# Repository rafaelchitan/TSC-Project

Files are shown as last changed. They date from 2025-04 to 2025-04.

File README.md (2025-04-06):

# Proiect TSC

## Chitan Rafael-Alexandru - 332CA

# Diagrama block

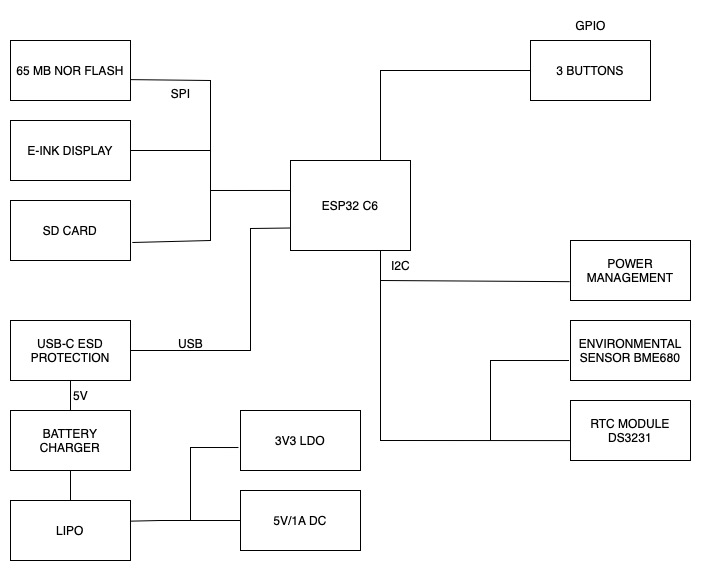
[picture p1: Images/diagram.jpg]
Diagrama


# Descrierea componentelor hardware

## Microcontroller – ESP32-C6

- **Arhitectura:** RISC-V 32-bit
- **Conectivitate:** WiFi 6, Bluetooth Low Energy 5.0
- **Interfete:** SPI, I2C, UART, PWM, GPIO
- **Consum redus:** suporta moduri de somn (deep sleep)

---

## E-Paper Display

- **Conectare:** 20 pini prin header dedicat
- **Control:** SPI + GPIO
  - Semnale: `EPD_CS`, `EPD_DC`, `EPD_RST`, `EPD_BUSY`, etc.
- **Avantaje:** consum 0 in standby, lizibilitate excelenta in lumina naturala

---

## Senzor de Mediu – BME688

- **Functii:** Temperatura, Umiditate, Presiune, Calitate aer (VOCs)
- **Comunicare:** I2C
  - SDA: `IO1`
  - SCL: `IO2`
- **Tensiune:** 3.3V
- **Adresa I2C:** `0x76`

---

## RTC – DS3231SN

- **Functie:** Timp real cu precizie ±2 ppm
- **Interfata:** I2C (SDA/SCL comune)
- **Backup:** Supercapacitor

---

## Alimentare si Baterie

### MAX17048 – Fuel Gauge

- **Functie:** Monitorizare nivel baterie LiPo
- **Comunicare:** I2C (`IO1`, `IO2`)

### MCP73831 – Battery Charging Controller

- **Incarcare:** 1 celula LiPo (USB → 3.7V)
- **Curent:** ~500 mA
- **Status LED:** Incarcare finalizata / in curs

### XC6204 – LDO Regulator

- **Intrare:** 5V (USB)
- **Iesire:** 3.3V
- **Curent maxim:** 200 mA
- **Consum in standby:** < 1 µA

---

## Stocare

### SD Card (microSD)

- **Interfata:** SPI (IO4–IO9)
- **Functie:** Salvare fisiere eBook, configurari

### NOR Flash – W25Q512JV (64MB)

- **Interfata:** SPI (dedicat: IO20–IO23)
- **Functie:** Stocare firmware, fonturi, assets

---

## Voltage Supervisor & Reset

- **Componenta:** BD52xx
- **Functie:** Monitorizare tensiune si reset sigur
- **Boot/Reset GPIO:** `IO0`

---

## I2C Extensii – Qwiic / Stemma QT

- **Conector:** 4 pini (3V3, GND, SDA, SCL)
- **Interfata:** I2C (`IO1`, `IO2`)
- **Compatibil:** Adafruit / SparkFun senzori si periferice

---

## Estimare Consum de Energie

| Componenta | Activ | Standby |
|---|---|---|
| ESP32-C6 | 80–150 mA | <10 µA |
| E-Paper | 20–30 mA | 0 µA |
| BME688 | 1.1 mA | 0.15 µA |
| RTC DS3231SN | 200 µA | 2 µA |
| SD Card | 20–100 mA | 0.2 µA |
| MAX17048 | 50 µA | 1 µA |
| NOR Flash | 20 mA | 5 µA |

---

## Test Pads & Protectie ESD

- **Protectii:** TVS diode pe USB, SPI si I2C
- **Test Pads:** disponibile pentru debugging si masuratori

---

## Pin Mapping – ESP32-C6

| Functie | GPIO Pins |
|---|---|
| SD Card (SPI) | IO4, IO5, IO6, IO9  |
| E-Paper Display | IO10–IO19 |
| I2C (RTC, Sensor, Fuel)| IO1 (SDA), IO2 (SCL)|
| SPI Flash extern | IO20–IO23 |
| Reset / Boot Button | IO0 |

## Bill of Materials
| Componenta | Link | Datasheet |
|---|---|---|
| BUTTON | [Model](https://industry.panasonic.com/global/en/products/control/switch/light-touch/number/evqpuj02k) | [Datasheet](https://www.lcsc.com/datasheet/lcsc_datasheet_2201121800_PANASONIC-EVQPUJ02K_C2936858.pdf) |
| CAPACITOR | [Model](https://componentsearchengine.com/part-view/R0402%201%25%20100%20K%20(RC0402FR-07100KL)/YAGEO) | [Datasheet](//efaidnbmnnnibpcajpcglclefindmkaj/https://www.resistor.com/assets/pdf/0402tstd.pdf) |
| CPH3225A | [Model](https://www.snapeda.com/parts/CPH3225A/Seiko+Instruments/view-part/?ref=eda) | [Datasheet](https://octopart.com/datasheet/cph3225a-seiko-25340571) |
| EVQPUJ02K | [Model](https://industry.panasonic.com/global/en/products/control/switch/light-touch/number/evqpuj02k) | [Datasheet](https://www.lcsc.com/datasheet/lcsc_datasheet_2201121800_PANASONIC-EVQPUJ02K_C2936858.pdf) |
| KP-1608SURCK | [Model](https://www.snapeda.com/parts/KP-1608SURCK/Kingbright/view-part/?ref=search&t=LED%200603) | [Datasheet](//efaidnbmnnnibpcajpcglclefindmkaj/https://media.elv.com/file/107153_led_surck1608_data.pdf) |
| USBLC6-2SC6Y | [Model](https://www.snapeda.com/parts/USBLC6-2SC6Y/STMicroelectronics/view-part/?ref=eda) | [Datasheet](https://www.digikey.com/en/htmldatasheets/production/1375342/0/0/1/usblc6-2sc6y) |
| SD0805S020S1R0 | [Model](https://ro.mouser.com/ProductDetail/KYOCERA-AVX/SD0805S020S1R0?qs=jCA%252BPfw4LHbpkAoSnwrdjw%3D%3D) | [Datasheet](https://www.alldatasheet.com/view.jsp?Searchword=SD0805S&sField=2) |
| PGB1010603MR | [Model](https://www.snapeda.com/parts/PGB1010603MR/Littelfuse/view-part/?ref=eda) | [Datasheet](https://www.alldatasheet.com/view.jsp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) |
| BD5229G-TR  | [Model](https://componentsearchengine.com/part-view/BD5229G-TR/ROHM%20Semiconductor) | [Datasheet](https://www.lcsc.com/datasheet/lcsc_datasheet_2201131330_ROHM-Semicon-BD5229G-TR_C962636.pdf) |
| XC6220A331MR-G | [Model](https://componentsearchengine.com/part-view/XC6220A331MR-G/Torex) | [Datasheet](https://www.alldatasheet.com/view.jsp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) |
| XC6220A331MR-G | [Model](https://componentsearchengine.com/part-view/XC6220A331MR-G/Torex) | [Datasheet](https://www.alldatasheet.com/view.jsp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) |
| USB4110-GF-A  | [Model](https://componentsearchengine.com/part-view/USB4110-GF-A/GCT%20(GLOBAL%20CONNECTOR%20TECHNOLOGY)) | [Datasheet](//efaidnbmnnnibpcajpcglclefindmkaj/https://gct.co/files/drawings/usb4110.pdf) |
| Adafruit | [Model](https://eu.mouser.com/ProductDetail/Adafruit/4208?qs=PzGy0jfpSMtbScLbr0L5dw%3D%3D) | [Datasheet](https://www.arrow.com/en/manufacturers/adafruit-industries/datasheets) |
| Bobina | [Model](https://store.comet.srl.ro/Catalogue/Product/43497/) | [Datasheet](https://www.scribd.com/document/814581278/Datasheet-Bobina) |
| PFMF | [Model](https://www.mouser.co.uk/ProductDetail/EPCOS-TDK/B72520T0350K062?qs=dEfas%2FXlABIszF52uu7vrg%3D%3D) | [Datasheet](https://ro.mouser.com/c/ds/circuit-protection/thermistors/resettable-fuses-pptc/?m=Schurter&series=PFMF) |
| DMG2305UX-7 | [Model](https://componentsearchengine.com/part-view/DMG2305UX-7/Diodes%20Incorporated) | [Datasheet](//efaidnbmnnnibpcajpcglclefindmkaj/https://www.mouser.com/datasheet/2/115/DMG2305UX-266242.pdf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) |
| Si1308EDL-T1-GE3 | [Model](https://componentsearchengine.com/part-view/SI1308EDL-T1-GE3/Vishay) | [Datasheet](https://www.alldatasheet.com/view.jsp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) |
| R0402 | [Model](https://componentsearchengine.com/part-view/R0402%201%25%20100%20K%20(RC0402FR-07100KL)/YAGEO) | [Datasheet](//efaidnbmnnnibpcajpcglclefindmkaj/https://www.resistor.com/assets/pdf/0402tstd.pdf) |
| BME680 | [Model](https://www.snapeda.com/parts/BME680/Bosch/view-part/?welcome=home) | [Datasheet](//efaidnbmnnnibpcajpcglclefindmkaj/https://www.bosch-sensortec.com/media/boschsensortec/downloads/datasheets/bst-bme680-ds001.pdf) |
| SMD Solder | [Model](https://grabcad.com/library/solder-jumpers-1) | [Datasheet]() |
| W25Q512JVEIQ | [Model](https://www.snapeda.com/parts/ESP32-C6-WROOM-1-N8/Espressif+Systems/view-part/?ref=eda) | [Datasheet](//efaidnbmnnnibpcajpcglclefindmkaj/https://www.mouser.com/datasheet/2/949/W25Q512JV_SPI_RevB_06252019_KMS-2487502.pdf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) |
| ESP32-C6-WROOM-1-N8 | [Model](https://www.snapeda.com/parts/ESP32-C6-WROOM-1-N8/Espressif+Systems/view-part/?ref=eda) | [Datasheet](//efaidnbmnnnibpcajpcglclefindmkaj/https://www.mouser.com/catalog/specsheets/Espressif_ESP32_C6_WROOM_1%20_Datasheet_V0.1_PRELIMINARY_en.pdf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) |
| DS3231SN# | [Model](https://www.snapeda.com/parts/DS3231SN%23/Analog+Devices/view-part/?ref=eda) | [Datasheet](https://www.alldatasheet.com/view.jsp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) |
| MAX17048G+T10 | [Model](https://www.snapeda.com/parts/MAX17048G+T10/Analog+Devices/view-part/?ref=eda) | [Datasheet](https://www.alldatasheet.com/view.jsp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) |
| MCP73831T-5ACI/OT | [Model](https://www.mouser.co.uk/ProductDetail/Microchip-Technology/MCP73831T-5ACI-OT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) | [Datasheet](//efaidnbmnnnibpcajpcglclefindmkaj/https://ww1.microchip.com/downloads/en/DeviceDoc/MCP73831-Family-Data-Sheet-DS20001984H.pdf) |

## Alte note aditionale

- Pentru a rezolva erorile datorate checkerului de design, am modificat dimensiunile unor componente.

- A fost nevoie sa realizez rutarea atat pe planul top, cat si pe cel bottom. Traseele de putere au fost plasate exclusiv pe planul top, evitandu-se astfel trecerea prin vias.

- Am realizat un plan de masa atat pe planul top, cat si pe cel bottom pentru a imbunatati integritatea semnalului si reducerea zgomotului.

- Componentele principale au fost plasate exact conform specificatiilor oferite pentru a asigura o corelare perfecta intre dimensiunile PCB-ului si cele ale carcasei, avand in vedere mereu plasarea componentelor astfel incat sa asigur ulterior o rutare eficienta. Bateria a fost plasata in spatiul ramas liber in carcasa.

- Alinierea a fost realizata in functie de conectorul USB, insa exista totusi mici diferente la amplasarea butoanelor, insa aceste diferente nu vor influenta functionalitatea acestora.

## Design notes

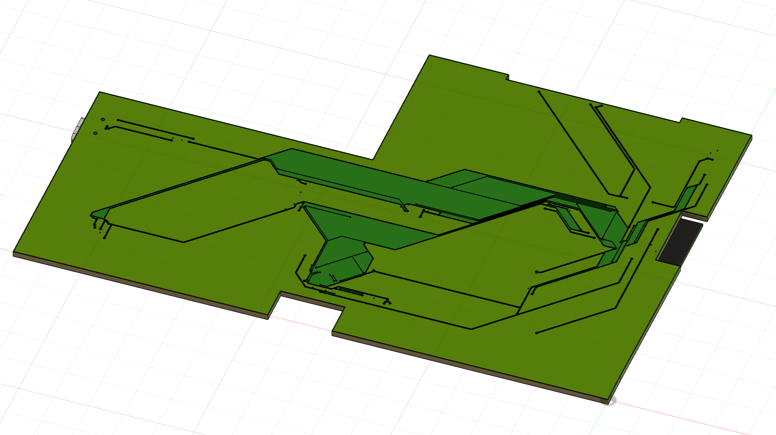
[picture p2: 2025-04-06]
Images/pcb-bottom.png

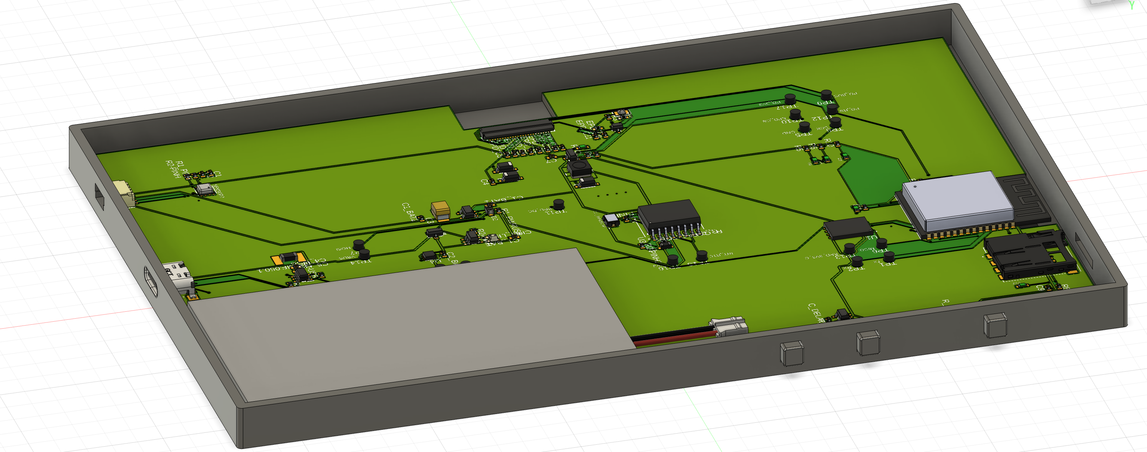
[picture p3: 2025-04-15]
Images/pcb-in-carcasa.png

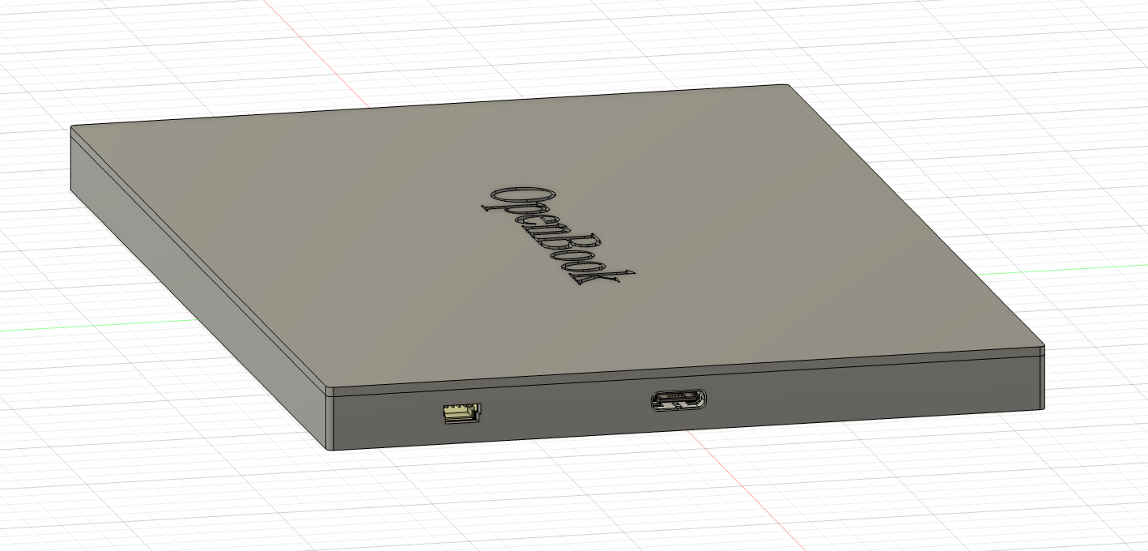
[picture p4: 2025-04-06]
Images/carcasa.png

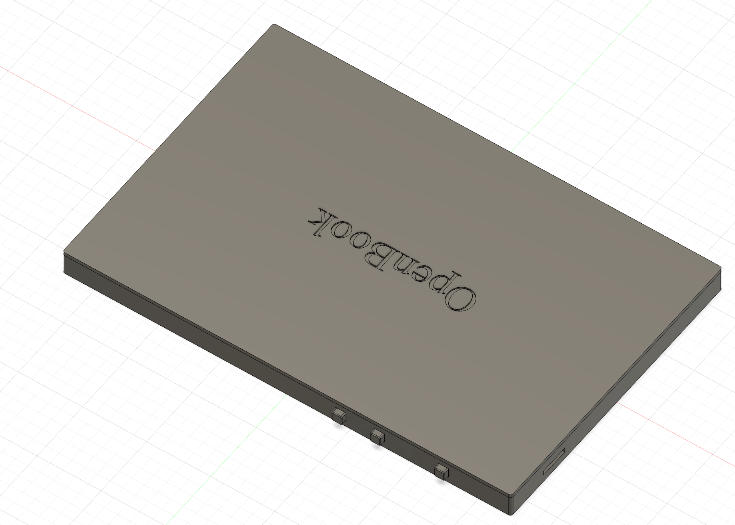
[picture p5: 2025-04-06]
Images/carcasa-top.png

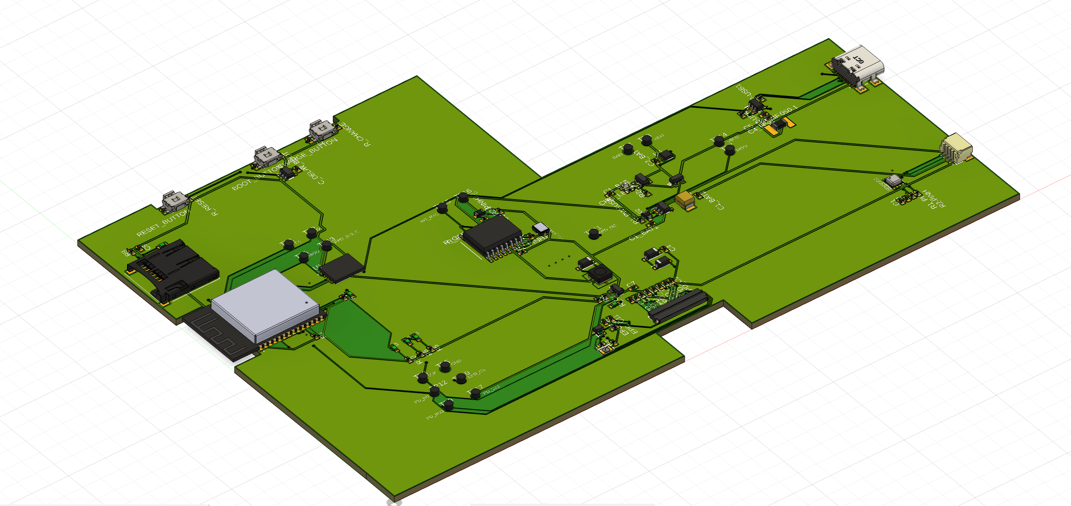
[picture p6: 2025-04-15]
Images/pcb-top.png

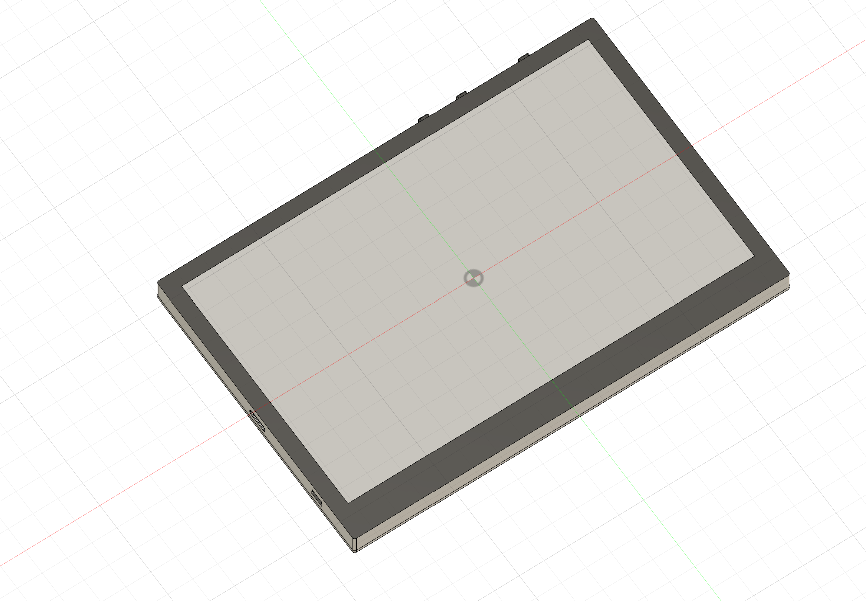
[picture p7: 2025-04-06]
Images/display.png

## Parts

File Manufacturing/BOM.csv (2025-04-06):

Qty | Value | Device | Package | Parts | Description | ARROW_PART_NUMBER | ARROW_PRICE-STOCK | AVAILABILITY | CENTROID_NOT_SPECIFIED | CHECK_PRICES | CODE | COPYRIGHT | DATASHEET | DESCRIPTION | DIGIKEY_DESCRIPTION | DIGIKEY_PART_NUMBER | HEIGHT | LEAD_FREE | MANUFACTURER_NAME | MANUFACTURER_PART_NUMBER | MF | MFR_NAME | MOUSER_PART_NUMBER | MOUSER_PRICE-STOCK | MOUSER_TESTING_PART_NUMBER | MOUSER_TESTING_PRICE-STOCK | MP | MPN | PACKAGE | POPULARITY | PREFIX | PRICE | PROD_ID | PURCHASE-URL | ROHS | SNAPEDA_LINK | SPICEMODEL | SPICEPREFIX | TEMPERATURE_RANGE_HIGH | TEMPERATURE_RANGE_LOW | TP_SIGNAL_NAME | VALUE
1 |  | ADAFRUIT_LEDCHIP-LED0603 | ADAFRUIT_CHIP-LED0603 | CHG_LED | LED
1 |  | SJ | SJ | SJ1 | SMD solder JUMPER |  |  |  |  |  |  |  |  |  |  |  |  |  |  |  |  |  |  |  |  |  |  |  |  | 3
1 | 0.1uF/50V | EAGLE-LTSPICE_CC0402 | EAGLE-LTSPICE_C0402 | EPD_C5 | CAPACITOR, European symbol |  |  |  |  |  |  |  |  |  |  |  |  |  |  |  |  |  |  |  |  |  |  |  |  |  |  |  |  |  |  |  | NONE | C
1 | 0.47 | ESP32_WROVER_EAGLE-LTSPICE_RR0402 | ESP32_WROVER_EAGLE-LTSPICE_R0402 | R3 | RESISTOR, European symbol |  |  |  |  |  |  |  |  |  |  |  |  |  |  |  |  |  |  |  |  |  |  |  |  |  |  |  |  |  |  |  | NONE | R
1 | 100K | ESP32_WROVER_EAGLE-LTSPICE_RR0402 | ESP32_WROVER_EAGLE-LTSPICE_R0402 | R1_PWRUSB | RESISTOR, European symbol |  |  |  |  |  |  |  |  |  |  |  |  |  |  |  |  |  |  |  |  |  |  |  |  |  |  |  |  |  |  |  | NONE | R
7 | 100nF | EAGLE-LTSPICE_CC0402 | EAGLE-LTSPICE_C0402 | C1, C2, C6, C8, C9, C10, C_DELAY | CAPACITOR, European symbol |  |  |  |  |  |  |  |  |  |  |  |  |  |  |  |  |  |  |  |  |  |  |  |  |  |  |  |  |  |  |  | NONE | C
1 | 100nF | ESP32_WROVER_EAGLE-LTSPICE_CC0402 | EAGLE-LTSPICE_C0402 | C4_USB | CAPACITOR, European symbol |  |  |  |  |  |  |  |  |  |  |  |  |  |  |  |  |  |  |  |  |  |  |  |  |  |  |  |  |  |  |  | NONE | C
1 | 100uF TANT | RCL_CPOL-EUCT3528 | RCL_CT3528 | C3 | POLARIZED CAPACITOR, European symbol |  |  |  |  |  |  |  |  |  |  |  |  |  |  |  |  |  |  |  |  |  |  |  |  | 0 |  |  |  |  |  |  |  | C
16 | 10K | ESP32_WROVER_EAGLE-LTSPICE_RR0402 | ESP32_WROVER_EAGLE-LTSPICE_R0402 | R1, R1_PINH, R1_PINH1, R2-PINH, R2-PINH1, R4, R5, R6, R7, R8, R9, R10, R_BOOT, R_CHANGE, R_CL1, R_RESET | RESISTOR, European symbol |  |  |  |  |  |  |  |  |  |  |  |  |  |  |  |  |  |  |  |  |  |  |  |  |  |  |  |  |  |  |  | NONE | R
1 | 10uF | EAGLE-LTSPICE_CC0402 | EAGLE-LTSPICE_C0402 | C7 | CAPACITOR, European symbol |  |  |  |  |  |  |  |  |  |  |  |  |  |  |  |  |  |  |  |  |  |  |  |  |  |  |  |  |  |  |  | NONE | C
1 | 112A-TAAR-R03_ATTEND | 112A-TAAR-R03_ATTEND | 112ATAARR03ATTEND | J4 | Micro SD Card Socket, Push-Push Type, Top Mount, SMT, H=1.83mm, 10u |  |  |  |  |  |  |  |  | Micro SD Card Socket | Push-Push Type | Top Mount | SMT | H=1.83mm | 10u |  |  | 1.9mm |  | ATTEND | 112A-TAAR-R03 ATTEND
1 | 15 | ESP32_WROVER_EAGLE-LTSPICE_RR0402 | ESP32_WROVER_EAGLE-LTSPICE_R0402 | R_CAPACITOR | RESISTOR, European symbol |  |  |  |  |  |  |  |  |  |  |  |  |  |  |  |  |  |  |  |  |  |  |  |  |  |  |  |  |  |  |  | NONE | R
1 | 1uF | EAGLE-LTSPICE_CC0402 | EAGLE-LTSPICE_C0402 | C5 | CAPACITOR, European symbol |  |  |  |  |  |  |  |  |  |  |  |  |  |  |  |  |  |  |  |  |  |  |  |  |  |  |  |  |  |  |  | NONE | C
9 | 1uF/50V | EAGLE-LTSPICE_CC0402 | EAGLE-LTSPICE_C0402 | EPD_C1, EPD_C2, EPD_C6, EPD_C7, EPD_C8, EPD_C9, EPD_C10, EPD_C11, EPD_C12 | CAPACITOR, European symbol |  |  |  |  |  |  |  |  |  |  |  |  |  |  |  |  |  |  |  |  |  |  |  |  |  |  |  |  |  |  |  | NONE | C
1 | 2.2 | ESP32_WROVER_EAGLE-LTSPICE_RR0402 | ESP32_WROVER_EAGLE-LTSPICE_R0402 | R2 | RESISTOR, European symbol |  |  |  |  |  |  |  |  |  |  |  |  |  |  |  |  |  |  |  |  |  |  |  |  |  |  |  |  |  |  |  | NONE | R
1 | 200 | ESP32_WROVER_EAGLE-LTSPICE_RR0402 | ESP32_WROVER_EAGLE-LTSPICE_R0402 | R1_BAT | RESISTOR, European symbol |  |  |  |  |  |  |  |  |  |  |  |  |  |  |  |  |  |  |  |  |  |  |  |  |  |  |  |  |  |  |  | NONE | R
2 | 20V/4.2A/52mΩ/1.4W | ESP32_WROVER_SPARKFUN-DISCRETESEMI_MOSFET_PCH-DMG2305UX-7 | ESP32_WROVER_SPARKFUN-DISCRETESEMI_SOT23-3 | Q1, Q2 | P-channel MOSFETs |  |  |  |  |  | DMG2305UX-7 |  |  |  |  |  |  |  |  |  |  |  |  |  |  |  |  |  |  |  |  |  | TRAN-14388 |  |  |  |  |  |  |  |  | 20V/4.2A/52mΩ/1.4W
1 | 2K | ESP32_WROVER_EAGLE-LTSPICE_RR0402 | ESP32_WROVER_EAGLE-LTSPICE_R0402 | R2_BAT | RESISTOR, European symbol |  |  |  |  |  |  |  |  |  |  |  |  |  |  |  |  |  |  |  |  |  |  |  |  |  |  |  |  |  |  |  | NONE | R
2 | 4.7uF | EAGLE-LTSPICE_CC0402 | EAGLE-LTSPICE_C0402 | C1_BAT, C2_BAT | CAPACITOR, European symbol |  |  |  |  |  |  |  |  |  |  |  |  |  |  |  |  |  |  |  |  |  |  |  |  |  |  |  |  |  |  |  | NONE | C
3 | 4.7uF | ESP32_WROVER_EAGLE-LTSPICE_CC0402 | EAGLE-LTSPICE_C0402 | C1_BAT1, C1_BAT2, C5_USB | CAPACITOR, European symbol |  |  |  |  |  |  |  |  |  |  |  |  |  |  |  |  |  |  |  |  |  |  |  |  |  |  |  |  |  |  |  | NONE | C
1 | 4.7uF/25V | EAGLE-LTSPICE_CC0402 | EAGLE-LTSPICE_C0402 | C4 | CAPACITOR, European symbol |  |  |  |  |  |  |  |  |  |  |  |  |  |  |  |  |  |  |  |  |  |  |  |  |  |  |  |  |  |  |  | NONE | C
2 | 5k1 | ESP32_WROVER_EAGLE-LTSPICE_RR0402 | ESP32_WROVER_EAGLE-LTSPICE_R0402 | R2-USB, R2-USB1 | RESISTOR, European symbol |  |  |  |  |  |  |  |  |  |  |  |  |  |  |  |  |  |  |  |  |  |  |  |  |  |  |  |  |  |  |  | NONE | R
1 | 68uH | 744043680IND_4828-WE-TPC_WRE | IND_4828-WE-TPC_WRE | L1 |  |  |  |  |  |  |  | Copyright (C) 2024 Ultra Librarian. All rights reserved. |  |  |  |  |  |  |  | 744043680 |  | Wurth Electronics
1 | BD5229G-TR | BD5229G-TR | SOT95P280X125-5N | IC1 | Voltage Detector with Adjustable Delay Time: CMOS processes are utilized to develop high precision, low current consumption CMOS reset ICs that allow arbitrary setting of the delay time. The extensive lineup includes both Nch Open Drain and CMOS output types in a wide range of detection voltages (from 2.3V to 6.0V, in 0.1V steps), enabling selection of the ideal solution based on customer requirements. In addition, the entire series is of course both lead-free and RoHS-compliant. |  |  |  |  |  |  |  |  | Voltage Detector with Adjustable Delay Time: CMOS processes are utilized to develop high precision | low current consumption CMOS reset ICs that allow arbitrary setting of the delay time. The extensive lineup includes both Nch Open Drain and CMOS output types in a wide range of detection voltages (from 2.3V to 6.0V | in 0.1V steps) | enabling selection of the ideal solution based on customer requirements. In addition | the entire series is of course both lead-free and RoHS-compliant. |  |  | 1.25mm |  | ROHM Semiconductor | BD5229G-TR |  |  | 755-BD5229G-TR | https://www.mouser.co.uk/ProductDetail/ROHM-Semiconductor/BD5229G-TR?qs=4kLU8WoGk0vvnhrrYwdszw%3D%3D
1 | BME688 | ESP32_WROVER_BME680_BME680 | ESP32_WROVER_BME680_PSON80P300X300X100-8N | SENSOR2 | Integrated Environmental Unit |  |  | Unavailable |  |  |  |  |  | Integrated Environmental Unit |  |  |  |  |  |  | Bosch Sensortec |  |  |  |  |  | BME680 |  | LGA-8 Bosch Tools |  |  | None
3 | BUTTON_CUSYOMV1 | BUTTON_CUSYOMV1 | MYBUTTON | BOOT_BUTTON, CHANGE_BUTTON, RESET_BUTTON
1 | CPH3225A | CPH3225A | CAPCP3225X100N | C10_SUPERCAP | Cap 0.011F 3.3V 1210 Flat Check availability |  |  | Not in stock |  | https://www.snapeda.com/parts/CPH3225A/Seiko+Instruments/view-part/?ref=eda |  |  |  | 11 mF (EDLC) Supercapacitor 3.3 V 1210 (3225 Metric) - - |  |  |  |  |  |  | Seiko Instruments |  |  |  |  |  | CPH3225A |  | 1210 Seiko |  |  | None |  | https://www.snapeda.com/api/url_track_click_mouser/?unipart_id=562593&manufacturer=Seiko Instruments&part_name=CPH3225A&search_term=None |  | https://www.snapeda.com/parts/CPH3225A/Seiko+Instruments/view-part/?ref=snap
1 | DS3231SN# | DS3231SN# | SOIC127P1032X265-16N | U3 | Real Time Clock Serial 16-Pin SOIC W T/R Check availability |  |  | In Stock |  | https://www.snapeda.com/parts/DS3231SN%23/Analog+Devices/view-part/?ref=eda |  |  |  | Extremely Accurate I²C-Integrated RTC/TCXO/Crystal |  |  |  |  |  |  | Analog Devices |  |  |  |  |  | DS3231SN# |  | SOIC-16 Maxim |  |  | None |  | https://www.snapeda.com/api/url_track_click_mouser/?unipart_id=99048&manufacturer=Analog Devices&part_name=DS3231SN#&search_term=None |  | https://www.snapeda.com/parts/DS3231SN%23/Analog+Devices/view-part/?ref=snap
1 | ESP32-C6-WROOM-1-N8 | ESP32-C6-WROOM-1-N8 | XCVR_ESP32-C6-WROOM-1-N8 | U2 | Check availability |  |  | In Stock |  | https://www.snapeda.com/parts/ESP32-C6-WROOM-1-N8/Espressif+Systems/view-part/?ref=eda |  |  |  | Multiprotocol Modules ESP32-C6 module | Wi-Fi 6 in 2.4 GHz band | Bluetooth 5 | Zigbee 3.0 and Thread. ESP34-WROOM Compatible - ENGINEERING SAMPLE |  |  |  |  |  |  | Espressif Systems |  |  |  |  |  | ESP32-C6-WROOM-1-N8 |  | None |  |  | None |  |  |  | https://www.snapeda.com/parts/ESP32-C6-WROOM-1-N8/Espressif+Systems/view-part/?ref=snap
1 | ESP32C6_VARISTORCN1812 | ESP32C6_VARISTORCN1812 | ESP32C6_VARISTOR_CT/CN1812 | PFMF.050.1 | VARISTOR |  |  |  |  |  |  |  |  |  |  |  |  |  |  |  |  |  |  |  |  |  |  |  |  | 0
2 | ESP32_WROVER_AVX---SD0805S020S1R0_AVX_SD0805S020S1R0_0_0AVX_SD0805S020S1R0_0_0 | ESP32_WROVER_AVX---SD0805S020S1R0_AVX_SD0805S020S1R0_0_0AVX_SD0805S020S1R0_0_0 | ESP32_WROVER_AVX---SD0805S020S1R0_AVX_SD0805S020S1R0_0 | D2, D7 | Schottky Barrier Rectifier Diode |  |  |  | No |  | SD0805S020S1R0 |  | http://datasheets.avx.com/schottky.pdf |  | DIODE SCHOTTKY 20V 1A 0805 | 478-7800-1-ND |  | yes |  |  | AVX |  | 581-SD0805S020S1R0 |  |  |  |  |  | 0805 (2012 metric) |  | D |  |  |  | yes |  |  |  | +125°C | -55°C
1 | ESP32_WROVER_SPARKFUN-IC-POWER_MCP73831 | ESP32_WROVER_SPARKFUN-IC-POWER_MCP73831 | ESP32_WROVER_SPARKFUN-IC-POWER_SOT23-5 | MCP73831 | MCP73831T Li-Ion, Li-Pol Controller |  |  |  |  |  |  |  |  |  |  |  |  |  |  |  |  |  |  |  |  |  |  |  |  |  |  |  | IC-09995
1 | FH34SRJ-24S-0.5SH_99_ | FH34SRJ-24S-0.5SH_99_ | FH34SRJ24S05SH99 | J1 | (0.50mm) Surface Mount, Right Angle |  |  |  |  |  |  |  |  | 24 Position FFC | FPC Connector Contacts | (0.50mm) Surface Mount | Right Angle |  |  | 1.1mm |  | Hirose | FH34SRJ-24S-0.5SH(99) |  |  | 798-FH34SRJ24S05SH99 | https://www.mouser.co.uk/ProductDetail/Hirose-Connector/FH34SRJ-24S-0.5SH99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
1 | MAX17048G+T10 | MAX17048G+T10 | SON50P200X200X80-9N | U4 | Check availability |  |  | In Stock |  | https://www.snapeda.com/parts/MAX17048G+T10/Analog+Devices/view-part/?ref=eda |  |  |  | 3µA 1-Cell/2-Cell Fuel Gauge with ModelGauge |  |  |  |  |  |  | Analog Devices |  |  |  |  |  | MAX17048G+T10 |  | TDFN-8 Maxim |  |  | None |  | https://www.snapeda.com/api/url_track_click_mouser/?unipart_id=329239&manufacturer=Analog Devices&part_name=MAX17048G+T10&search_term=None |  | https://www.snapeda.com/parts/MAX17048G+T10/Analog+Devices/view-part/?ref=snap
3 | MBR0530 | MBR0530 | SOD3716X135N | D3, D4, D5 | ON SEMICONDUCTOR - MBR0530 - DIODE, SCHOTTKY, 0.5A, 30V, SOD-123 |  |  | In Stock |  | https://www.snapeda.com/parts/MBR0530/Onsemi/view-part/?ref=eda |  |  |  | Diode Schottky 30 V 500mA Surface Mount SOD-123 |  |  |  |  |  |  | ON Semiconductor |  |  |  |  |  | MBR0530 |  | SOD-123-2 ON Semiconductor |  |  | None |  | https://www.snapeda.com/api/url_track_click_mouser/?unipart_id=179458&manufacturer=ON Semiconductor&part_name=MBR0530&search_term=None |  | https://www.snapeda.com/parts/MBR0530/Onsemi/view-part/?ref=snap
6 | PGB1010603MR | PGB1010603MR | DIOC1608X36N | D6, D8, D9, D10, D11, D12 | Check availability |  |  | In Stock |  | https://www.snapeda.com/parts/PGB1010603MR/Littelfuse/view-part/?ref=eda |  |  |  | 150V (Typ) Clamp - Ipp Tvs Diode Surface Mount 0603 (1608 Metric) |  |  |  |  |  |  | Littelfuse Inc. |  |  |  |  |  | PGB1010603MR |  | 0603 Littelfuse Inc. |  |  | None |  | https://www.snapeda.com/api/url_track_click_mouser/?unipart_id=5659453&manufacturer=Littelfuse Inc.&part_name=PGB1010603MR&search_term=None |  | https://www.snapeda.com/parts/PGB1010603MR/Littelfuse/view-part/?ref=snap
1 | QWIIC_RIGHT_ANGLE | QWIIC_CONNECTORJS-1MM | JST04_1MM_RA | J3 | SparkFun I2C Standard Qwiic Connector |  |  |  |  |  |  |  |  |  |  |  |  |  |  |  |  |  |  |  |  |  |  |  |  |  |  |  | CONN-13694 |  |  |  |  |  |  |  |  | QWIIC_RIGHT_ANGLE
1 | SAMACSYS_PARTS_USB4110-GF-A | SAMACSYS_PARTS_USB4110-GF-A | SAMACSYS_PARTS_USB4110GFA | J2 | CONN USB 2.0 TYPE-C R/A SMT |  |  |  |  |  |  |  |  | CONN USB 2.0 TYPE-C R/A SMT |  |  | 3.26mm |  | GCT (GLOBAL CONNECTOR TECHNOLOGY) | USB4110-GF-A |  |  | 640-USB4110-GF-A | https://www.mouser.co.uk/ProductDetail/GCT/USB4110-GF-A?qs=KUoIvG%2F9IlYiZvIXQjyJeA%3D%3D
1 | SI1308EDL-T1-GE3 | SI1308EDL-T1-GE3 | SOT65P210X110-3N | Q3 | MOSFET N-Ch 30V 1.5A TrenchFET SC70 Vishay Si1308EDL-T1-GE3 N-channel MOSFET Transistor, 1.5 A, 30 V, 3-Pin SC-70 |  |  | In Stock |  | https://www.snapeda.com/parts/SI1308EDL-T1-GE3/Vishay+Siliconix/view-part/?ref=eda |  |  |  | Si1308EDL-T1-GE3 N-channel MOSFET Transistor | 1.5 A | 30 V | 3-Pin SC-70 | Siliconix / Vishay SI1308EDL-T1-GE3 |  |  |  |  |  |  | Vishay Siliconix |  |  |  |  |  | SI1308EDL-T1-GE3 |  | SOT-323 Vishay Semiconductor |  |  | None |  | https://www.snapeda.com/api/url_track_click_mouser/?unipart_id=274603&manufacturer=Vishay Siliconix&part_name=SI1308EDL-T1-GE3&search_term=None |  | https://www.snapeda.com/parts/SI1308EDL-T1-GE3/Vishay+Siliconix/view-part/?ref=snap
17 | TPTP20R | TPTP20R | TP20R | TP1, TP2, TP3, TP4, TP5, TP6, TP7, TP8, TP9, TP10, TP11, TP12, TP13, TP14, TP15, TP16, TP17 | Test pad |  |  |  |  |  |  |  |  |  |  |  |  |  |  |  |  |  |  |  |  |  |  |  |  | 2
1 | USBLC6-2SC6Y | USBLC6-2SC6Y | SOT95P280X145-6N | D1 | Low Cap. ESD Protection Auto SOT-23-6 STMicroelectronics USBLC6-2SC6Y, Dual Uni-Directional TVS Diode Array, 6-Pin SOT-23 |  |  | In Stock |  | https://www.snapeda.com/parts/USBLC6-2SC6Y/STMicroelectronics/view-part/?ref=eda |  |  |  | 17V Clamp 5A (8/20µs) Ipp Tvs Diode Surface Mount SOT-23-6 |  |  |  |  |  |  | STMicroelectronics |  |  |  |  |  | USBLC6-2SC6Y |  | SOT-23-6 STMicroelectronics |  |  | None |  |  |  | https://www.snapeda.com/parts/USBLC6-2SC6Y/STMicroelectronics/view-part/?ref=snap
1 | W25Q512JVEIQ | W25Q512JVEIQ | SON127P600X800X80-9N | U1 | Check availability |  |  | In Stock |  | https://www.snapeda.com/parts/W25Q512JVEIQ/Winbond+Electronics/view-part/?ref=eda |  |  |  | FLASH - NOR Memory IC 512Mb (64M x 8) SPI - Quad I/O 133 MHz 8-WSON (8x6) |  |  |  |  |  |  | Winbond Electronics |  |  |  |  |  | W25Q512JVEIQ |  | Package |  |  | None |  |  |  | https://www.snapeda.com/parts/W25Q512JVEIQ/Winbond+Electronics/view-part/?ref=snap
1 | XC6220A331MR-G | XC6220A331MR-G | SOT95P280X120-5N | IC4 | LDO Voltage Regulators |  |  |  |  |  |  |  |  | LDO Voltage Regulators |  |  | 1.2mm |  | Torex | XC6220A331MR-G |  |  | 865-XC6220A331MR-G | https://www.mouser.co.uk/ProductDetail/Torex-Semiconductor/XC6220A331MR-G?qs=AsjdqWjXhJ8ZSWznL1J0gg%3D%3D

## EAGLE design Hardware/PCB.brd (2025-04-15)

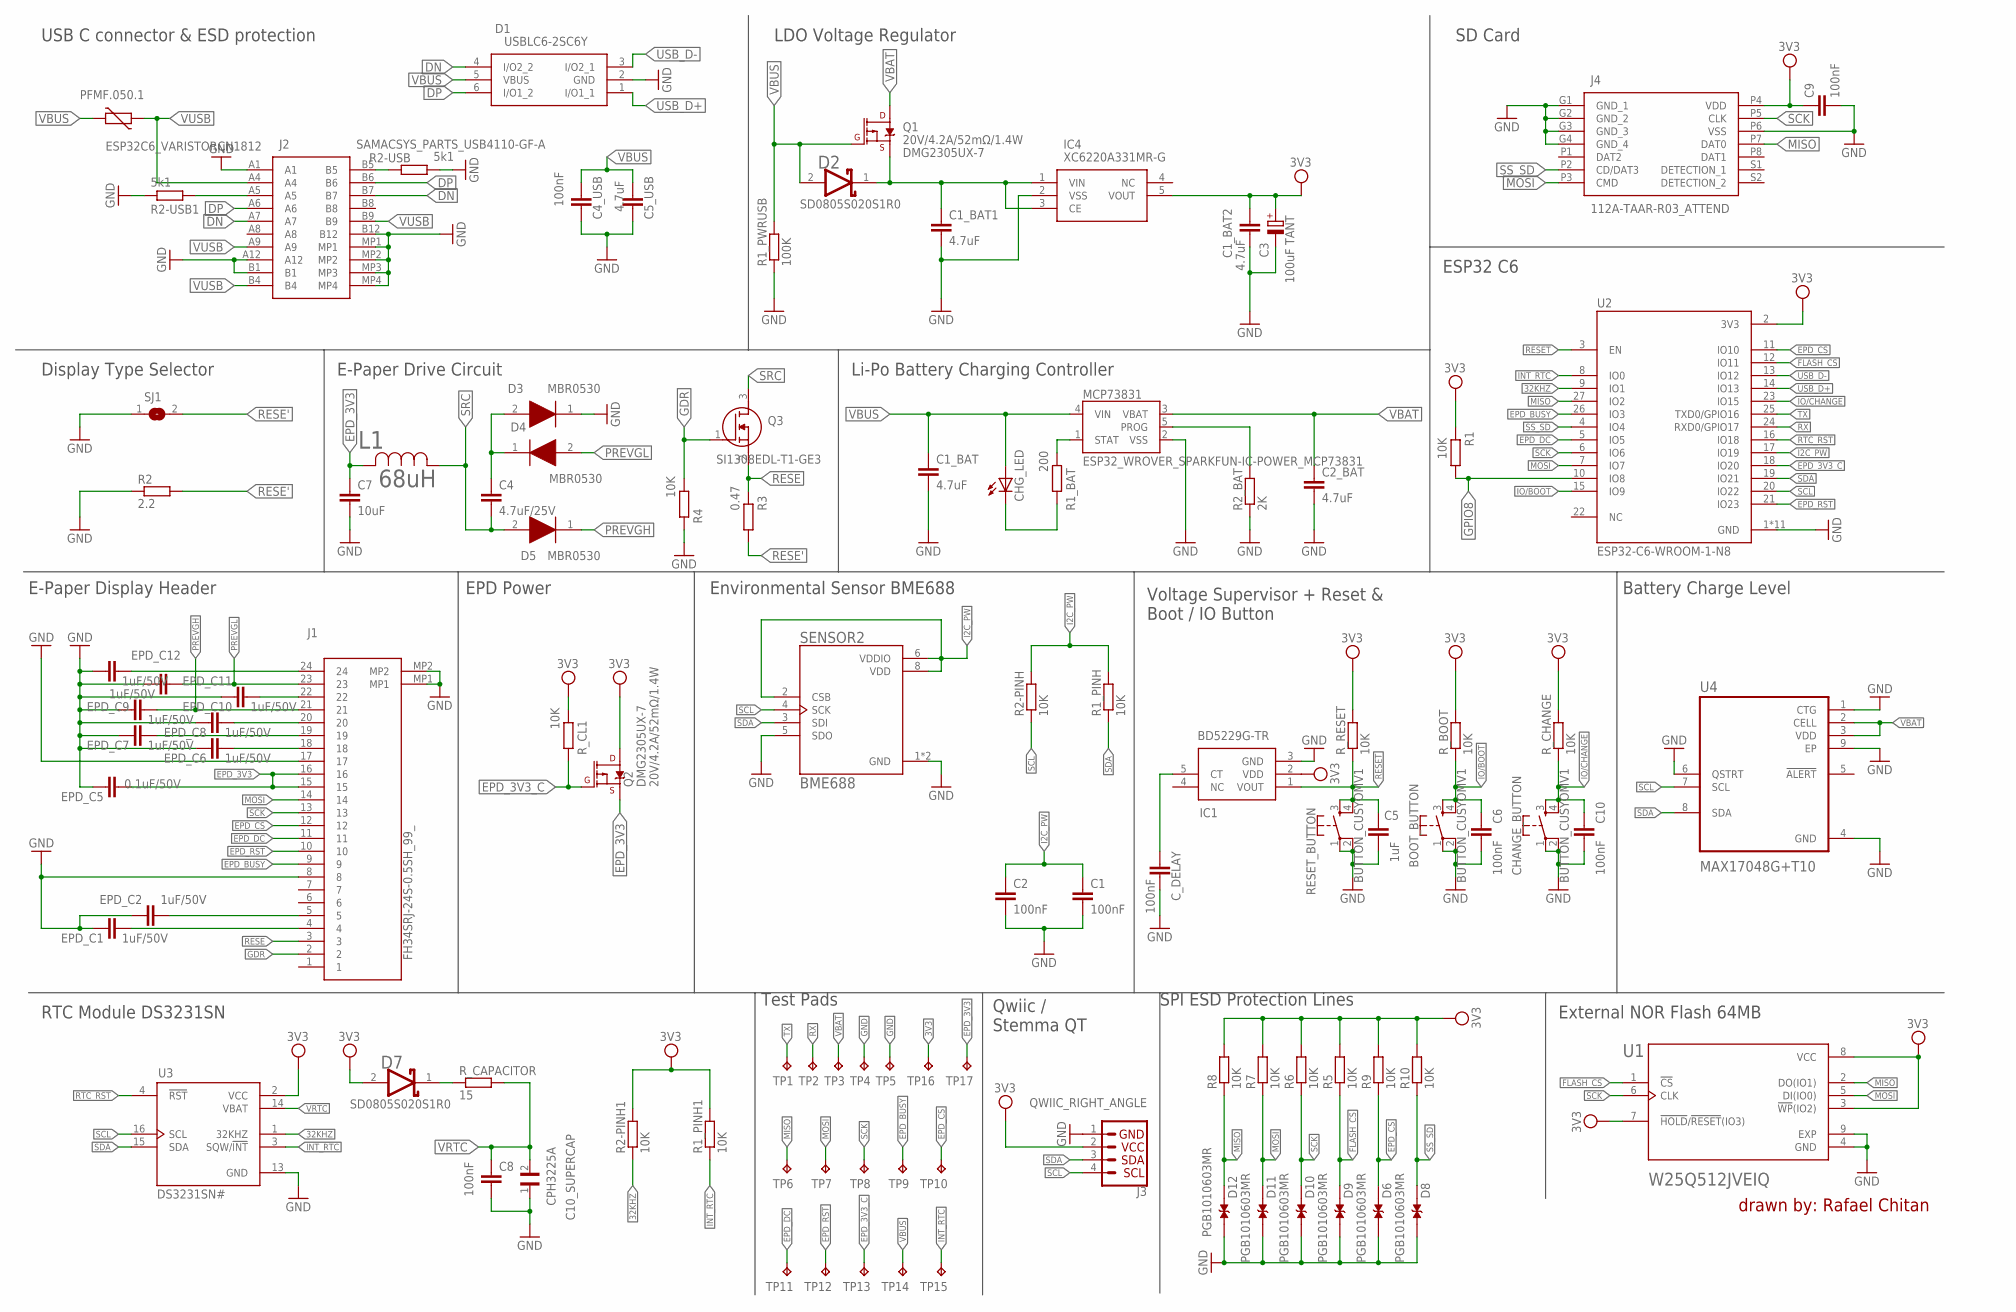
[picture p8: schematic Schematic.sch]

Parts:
BOOT_BUTTON: BUTTON_CUSYOMV1; MYBUTTON
C1, C2, C4_USB, C6, C8, C9, C10: 100nF; EAGLE-LTSPICE_C0402
C1_BAT, C1_BAT1, C1_BAT2, C2_BAT, C5_USB: 4.7uF; EAGLE-LTSPICE_C0402
C3: 100uF TANT; RCL_CT3528
C4: 4.7uF/25V; EAGLE-LTSPICE_C0402
C5: 1uF; EAGLE-LTSPICE_C0402
C7: 10uF; EAGLE-LTSPICE_C0402
C10_SUPERCAP: CPH3225A; CAPCP3225X100N
CHANGE_BUTTON: BUTTON_CUSYOMV1; MYBUTTON
CHG_LED: ADAFRUIT_LEDCHIP-LED0603; ADAFRUIT_CHIP-LED0603
C_DELAY: 100nF; EAGLE-LTSPICE_C0402
D1: USBLC6-2SC6Y; SOT95P280X145-6N
D2, D7: ESP32_WROVER_AVX---SD0805S020S1R0_AVX_SD0805S020S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; ESP32_WROVER_AVX---SD0805S020S1R0_AVX_SD0805S020S1R0_0
D3, D4, D5: MBR0530; SOD3716X135N
D6, D8, D9, D10, D11, D12: PGB1010603MR; DIOC1608X36N
EPD_C1, EPD_C2, EPD_C6, EPD_C7, EPD_C8, EPD_C9, EPD_C10, EPD_C11, EPD_C12: 1uF/50V; EAGLE-LTSPICE_C0402
EPD_C5: 0.1uF/50V; EAGLE-LTSPICE_C0402
IC1: BD5229G-TR; SOT95P280X125-5N
IC4: XC6220A331MR-G; SOT95P280X120-5N
J1: FH34SRJ-24S-0.5SH_99_; FH34SRJ24S05SH99
J2: SAMACSYS_PARTS_USB4110-GF-A; SAMACSYS_PARTS_USB4110GFA
J3: QWIIC_RIGHT_ANGLE; JST04_1MM_RA
J4: 112A-TAAR-R03_ATTEND; 112ATAARR03ATTEND
L1: 68uH; IND_4828-WE-TPC_WRE
MCP73831: ESP32_WROVER_SPARKFUN-IC-POWER_MCP73831; ESP32_WROVER_SPARKFUN-IC-POWER_SOT23-5
PFMF.050.1: ESP32C6_VARISTORCN1812; ESP32C6_VARISTOR_CT/CN1812
Q1, Q2: 20V/4.2A/52mΩ/1.4W; ESP32_WROVER_SPARKFUN-DISCRETESEMI_SOT23-3
Q3: SI1308EDL-T1-GE3; SOT65P210X110-3N
R1, R1_PINH, R1_PINH1, R2-PINH, R2-PINH1, R4, R5, R6, R7, R8, R9, R10: 10K; ESP32_WROVER_EAGLE-LTSPICE_R0402
R1_BAT: 200; ESP32_WROVER_EAGLE-LTSPICE_R0402
R1_PWRUSB: 100K; ESP32_WROVER_EAGLE-LTSPICE_R0402
R2: 2.2; ESP32_WROVER_EAGLE-LTSPICE_R0402
R2-USB, R2-USB1: 5k1; ESP32_WROVER_EAGLE-LTSPICE_R0402
R2_BAT: 2K; ESP32_WROVER_EAGLE-LTSPICE_R0402
R3: 0.47; ESP32_WROVER_EAGLE-LTSPICE_R0402
RESET_BUTTON: BUTTON_CUSYOMV1; MYBUTTON
R_BOOT: 10K; ESP32_WROVER_EAGLE-LTSPICE_R0402
R_CAPACITOR: 15; ESP32_WROVER_EAGLE-LTSPICE_R0402
R_CHANGE: 10K; ESP32_WROVER_EAGLE-LTSPICE_R0402
R_CL1: 10K; ESP32_WROVER_EAGLE-LTSPICE_R0402
R_RESET: 10K; ESP32_WROVER_EAGLE-LTSPICE_R0402
SENSOR2: BME688; ESP32_WROVER_BME680_PSON80P300X300X100-8N
SJ1: SJ
TP1, TP2, TP3, TP4, TP5, TP6, TP7, TP8, TP9, TP10, TP11, TP12, TP13, TP14, TP15, TP16, TP17: TPTP20R; TP20R
U1: W25Q512JVEIQ; SON127P600X800X80-9N
U2: ESP32-C6-WROOM-1-N8; XCVR_ESP32-C6-WROOM-1-N8
U3: DS3231SN#; SOIC127P1032X265-16N
U4: MAX17048G+T10; SON50P200X200X80-9N

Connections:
3V3: C1_BAT2.1, C3.+, C9.1, D7.2 (ANODE), IC1.2 (VDD), IC4.5 (VOUT), J3.2, J4.P4 (VDD), Q2.3 (D), R1.2, R1_PINH1.2, R2-PINH1.2, R5.2, R6.2, R7.2, R8.2, R9.2, R10.2, R_BOOT.2, R_CHANGE.2, R_CL1.2, R_RESET.2, TP16.TP, U1.3 (!WP!(IO2)), U1.7 (!HOLD!/!RESET!(IO3)), U1.8 (VCC), U2.2 (3V3), U3.2 (VCC)
32KHZ: R2-PINH1.1, U2.9 (IO1), U3.1 (32KHZ)
DN: D1.4 (I/O2_2), J2.A7, J2.B7
DP: D1.6 (I/O1_2), J2.A6, J2.B6
EPD_3V3: C7.1, EPD_C5.2, J1.15, J1.16, L1.2, Q2.2 (S), TP17.TP
EPD_3V3_C: Q2.1 (G), R_CL1.1, TP13.TP, U2.18 (IO20)
EPD_BUSY: J1.9, TP9.TP, U2.26 (IO3)
EPD_CS: D6.2, J1.12, R9.1, TP10.TP, U2.11 (IO10)
EPD_DC: J1.11, TP11.TP, U2.5 (IO5)
EPD_RST: J1.10, TP12.TP, U2.21 (IO23)
FLASH_CS: D9.2, R5.1, U1.1 (!CS), U2.12 (IO11)
GDR: J1.2, Q3.1 (G), R4.2
GND: BOOT_BUTTON.1, BOOT_BUTTON.2, C1.2, C1_BAT.2, C1_BAT1.2, C1_BAT2.2, C2.2, C2_BAT.2, C3.-, C4_USB.2, C5.2, C5_USB.2, C6.2, C7.2, C8.2, C9.2, C10.2, C10_SUPERCAP.1, CHANGE_BUTTON.1, CHANGE_BUTTON.2, C_DELAY.2, D1.2 (GND), D3.1 (K), D6.1, D8.1, D9.1, D10.1, D11.1, D12.1, EPD_C1.1, EPD_C2.1, EPD_C5.1, EPD_C6.1, EPD_C7.1, EPD_C8.1, EPD_C9.1, EPD_C10.1, EPD_C11.1, EPD_C12.1, IC1.3 (GND), IC4.2 (VSS), J1.8, J1.17, J1.MP1, J1.MP2, J2.A1, J2.A12, J2.B1, J2.B12, J2.MP1, J2.MP2, J2.MP3, J2.MP4, J3.1, J4.G1 (GND_1), J4.G2 (GND_2), J4.G3 (GND_3), J4.G4 (GND_4), J4.P6 (VSS), MCP73831.2 (VSS), R1_PWRUSB.1, R2.1, R2-USB.2, R2-USB1.1, R2_BAT.1, R4.1, RESET_BUTTON.1, RESET_BUTTON.2, SENSOR2.1 (GND), SENSOR2.5 (SDO), SENSOR2.7 (GND), SJ1.1, TP4.TP, TP5.TP, U1.4 (GND), U1.9 (EXP), U2.1 (GND), U2.28 (GND), U2.29_1 (GND), U2.29_2 (GND), U2.29_3 (GND), U2.29_4 (GND), U2.29_5 (GND), U2.29_6 (GND), U2.29_7 (GND), U2.29_8 (GND), U2.29_9 (GND), U3.13 (GND), U4.1 (CTG), U4.4 (GND), U4.6 (QSTRT), U4.9 (EP)
GPIO8: R1.1, U2.10 (IO8)
I2C_PW: C1.1, C2.1, R1_PINH.2, R2-PINH.2, SENSOR2.2 (CSB), SENSOR2.6 (VDDIO), SENSOR2.8 (VDD), U2.17 (IO19)
INT_RTC: R1_PINH1.1, TP15.TP, U2.8 (IO0), U3.3 (SQW/!INT)
IO/BOOT: BOOT_BUTTON.3, BOOT_BUTTON.4, C6.1, R_BOOT.1, U2.15 (IO9)
IO/CHANGE: C10.1, CHANGE_BUTTON.3, CHANGE_BUTTON.4, R_CHANGE.1, U2.23 (IO15)
MISO: D12.2, J4.P7 (DAT0), R8.1, TP6.TP, U1.2 (DO(IO1)), U2.27 (IO2)
MOSI: D11.2, J1.14, J4.P3 (CMD), R7.1, TP7.TP, U1.5 (DI(IO0)), U2.7 (IO7)
unnamed: J2.A5, R2-USB1.2
unnamed: J2.B5, R2-USB.1
unnamed: C1_BAT1.1, D2.1 (CATHODE), IC4.1 (VIN), IC4.3 (CE), Q1.2 (S)
unnamed: C4.1, D3.2 (A), D4.1 (K)
unnamed: MCP73831.5 (PROG), R2_BAT.2
unnamed: MCP73831.1 (STAT), R1_BAT.2
unnamed: CHG_LED.C, R1_BAT.1
unnamed: EPD_C12.2, J1.24
unnamed: EPD_C6.2, J1.18
unnamed: EPD_C7.2, J1.19
unnamed: EPD_C8.2, J1.20
unnamed: EPD_C10.2, J1.22
unnamed: EPD_C2.2, J1.5
unnamed: EPD_C1.2, J1.4
unnamed: C_DELAY.1, IC1.5 (CT)
unnamed: D7.1 (CATHODE), R_CAPACITOR.1
PREVGH: D5.1 (K), EPD_C9.2, J1.21
PREVGL: D4.2 (A), EPD_C11.2, J1.23
RESE: J1.3, Q3.2 (S), R3.2
RESE': R2.2, R3.1, SJ1.2
RESET: C5.1, IC1.1 (VOUT), RESET_BUTTON.3, RESET_BUTTON.4, R_RESET.1, U2.3 (EN)
RTC_RST: U2.16 (IO18), U3.4 (!RST)
RX: TP2.TP, U2.24 (RXD0/GPIO17)
SCK: D10.2, J1.13, J4.P5 (CLK), R6.1, TP8.TP, U1.6 (CLK), U2.6 (IO6)
SCL: J3.4, R2-PINH.1, SENSOR2.4 (SCK), U2.20 (IO22), U3.16 (SCL), U4.7 (SCL)
SDA: J3.3, R1_PINH.1, SENSOR2.3 (SDI), U2.19 (IO21), U3.15 (SDA), U4.8 (SDA)
SRC: C4.2, D5.2 (A), L1.1, Q3.3 (D)
SS_SD: D8.2, J4.P2 (CD/DAT3), R10.1, U2.4 (IO4)
TX: TP1.TP, U2.25 (TXD0/GPIO16)
USB_D+: D1.1 (I/O1_1), U2.14 (IO13)
USB_D-: D1.3 (I/O2_1), U2.13 (IO12)
VBAT: C2_BAT.1, MCP73831.3 (VBAT), Q1.3 (D), TP3.TP, U4.2 (CELL), U4.3 (VDD)
VBUS: C1_BAT.1, C4_USB.1, C5_USB.1, CHG_LED.A, D1.5 (VBUS), D2.2 (ANODE), MCP73831.4 (VIN), PFMF.050.1.2, Q1.1 (G), R1_PWRUSB.2, TP14.TP
VRTC: C8.1, C10_SUPERCAP.2, R_CAPACITOR.2, U3.14 (VBAT)
VUSB: J2.A4, J2.A9, J2.B4, J2.B9, PFMF.050.1.1

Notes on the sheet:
USB C connector & ESD protection
LDO Voltage Regulator
SD Card
Display Type Selector
E-Paper Drive Circuit
Li-Po Battery Charging Controller
ESP32 C6
E-Paper Display Header
EPD Power
Environmental Sensor BME688
Voltage Supervisor + Reset & Boot / IO Button
Battery Charge Level
RTC Module DS3231SN
Test Pads
Qwiic / Stemma QT
SPI ESD Protection Lines
External NOR Flash 64MB
drawn by: Rafael Chitan

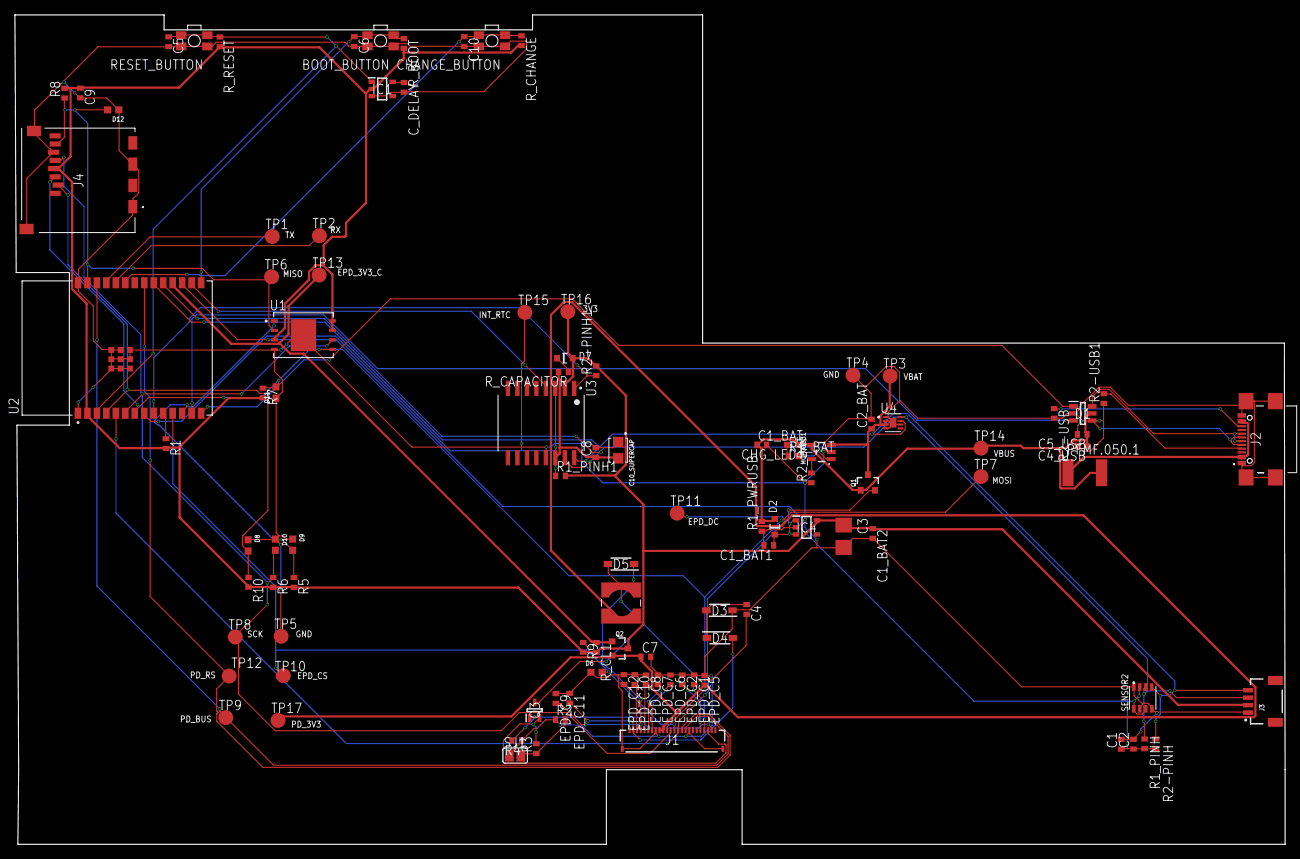
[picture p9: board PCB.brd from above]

Board: 2 copper layers, 170.3 x 111.2 mm, 103 parts (0 on the bottom side), 55 nets.

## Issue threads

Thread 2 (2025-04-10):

Model 3D

IonutBoraciu, 2025-04-10:
112A-TAAR-R03_ATTEND nu are modelul 3D setat bine, poti sa iei un model de aici: [Comet](https://store.comet.srl.ro/Catalogue/Product/43497/)
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

rafaelchitan, 2025-04-15:
Am inlocuit componenta cu modelul specificat de tine

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

Closed 2025-04-15.

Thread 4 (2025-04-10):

Fisier lipsa

IonutBoraciu, 2025-04-10:
Exploaded view lipseste

Cam asa ar trebui sa arate unul :

Si ar trebui sa se afle in Mechanical/

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

rafaelchitan, 2025-04-15:
Am realizat si exploaded view dupa modelul tau

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

Closed 2025-04-15.

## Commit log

2025-04-06 Project uploded
    [BOM.csv, PCB.brd, PNP.csv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]
2025-04-06 Added more text clarifications to PCB
    [PCB.brd]
2025-04-15 Resolved the raised issues
    [PCB.brd, Schematic.sch]

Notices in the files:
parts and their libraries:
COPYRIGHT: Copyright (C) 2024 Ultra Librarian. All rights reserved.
